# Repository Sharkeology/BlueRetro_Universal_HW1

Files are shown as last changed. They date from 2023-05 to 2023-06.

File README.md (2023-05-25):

# BlueRetro Universal HW1
A basic board meant to be used with the [BlueRetro project](https://github.com/darthcloud/BlueRetro) to simplify basic “HW1” internal installation in various supported consoles. Including onboard level shifting 3.3v regulation for consoles which don’t provide it.

### Bill of Materials
- [ESP-WROOM-32 Module](https://www.espressif.com/sites/default/files/documentation/esp32-wroom-32_datasheet_en.pdf)
- 2 x [TXS0108E 8-Bit Bi-directional, Level-Shifting, Voltage Translator](https://www.ti.com/lit/ds/symlink/txs0108e.pdf)
- 0805 1kΩ Pull-up Resistor for TXS0108E
- [AMS1117-3.3 3.3V 1A Low Dropout Voltage Regulator](http://www.advanced-monolithic.com/pdf/ds1117.pdf)
- 2 x 0805 Decoupling Capacitors for AMS1117 (I'm unsure of appropriate values, 1μF is what I used)

TXS0108EPWR Footprint and symbol courtesy of [SnapEDA](https://www.snapeda.com/parts/TXS0108EPWR/Texas%20Instruments/view-part/),
BlueRetro logo created by [HumbleBazooka](https://twitter.com/humblebazooka).

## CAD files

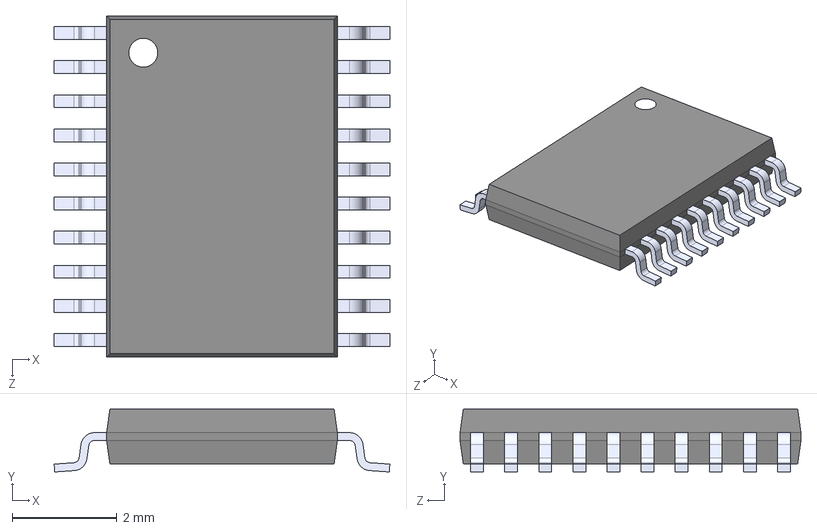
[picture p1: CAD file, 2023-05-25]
assets/TXS0108EPWR/TXS0108EPWR.step
6.40 x 1.20 x 6.50 mm

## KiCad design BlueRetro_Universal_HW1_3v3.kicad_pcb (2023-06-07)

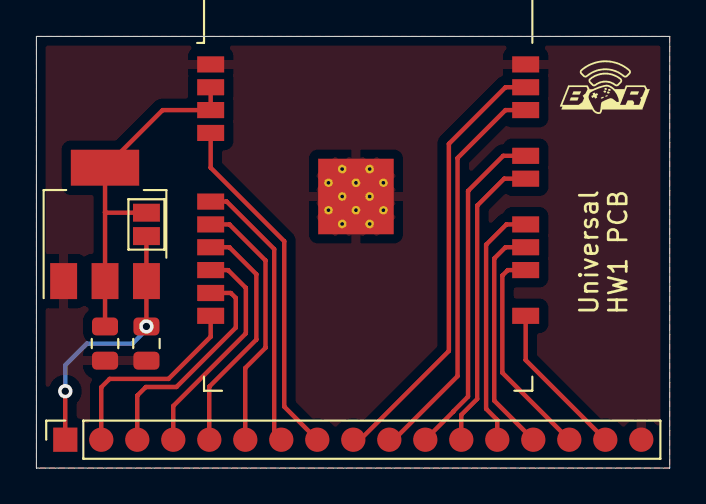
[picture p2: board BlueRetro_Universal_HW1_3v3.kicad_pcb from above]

Board: 2 copper layers, 35.2 x 24.0 mm, 6 parts (0 on the bottom side), 18 nets.

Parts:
C1, C2: 1uF; C_0805_2012Metric
J1: Conn_01x17; PinSocket_1x17_P2.00mm_Vertical
JP1: SolderJumper_2_Open; SolderJumper-2_P1.3mm_Open_Pad1.0x1.5mm
U1: AMS1117-3.3; SOT-223-3_TabPin2
U2: ESP32-WROOM-32

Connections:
+3V3: C2.1, JP1.2 (B), U1.2 (VO), U2.2 (VDD), U2.3 (EN)
+5V: C1.1, J1.1, JP1.1 (A), U1.3 (VI)
GND: C1.2, C2.2, J1.17, U1.1 (GND), U2.1 (GND), U2.38 (GND), U2.39 (GND)
IO3: J1.11, U2.34 (RXD0/IO3)
IO5: J1.15, U2.29 (IO5)
IO16: J1.16, U2.27 (IO16)
IO18: J1.14, U2.30 (IO18)
IO19: J1.13, U2.31 (IO19)
IO21: J1.12, U2.33 (IO21)
IO22: J1.10, U2.36 (IO22)
IO23: J1.9, U2.37 (IO23)
IO25: J1.4, U2.10 (IO25)
IO26: J1.3, U2.11 (IO26)
IO27: J1.2, U2.12 (IO27)
IO32: J1.6, U2.8 (IO32)
IO33: J1.5, U2.9 (IO33)
IO35: J1.7, U2.7 (IO35)
IO36: J1.8, U2.4 (SENSOR_VP)

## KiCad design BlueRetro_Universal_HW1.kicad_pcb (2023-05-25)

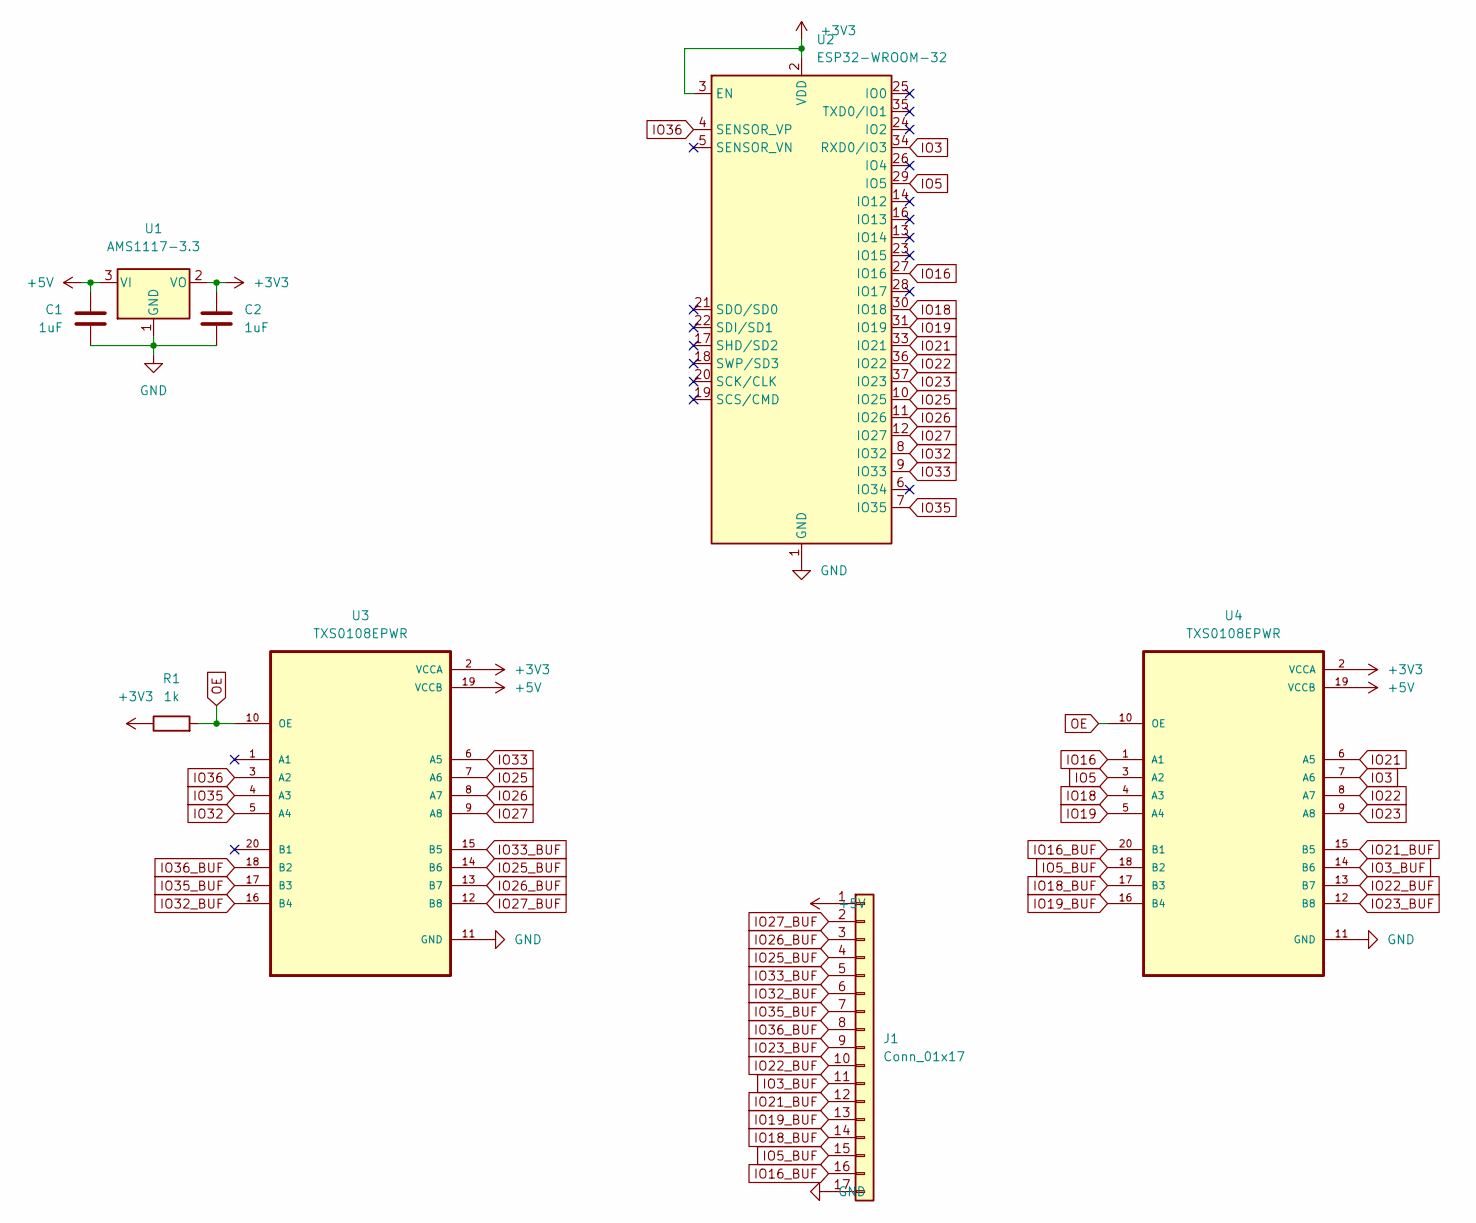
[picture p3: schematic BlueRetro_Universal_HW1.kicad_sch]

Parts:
C1, C2: 1uF; C_0805_2012Metric
J1: Conn_01x17; PinSocket_1x17_P2.00mm_Vertical
R1: 1k; R_0805_2012Metric
U1: AMS1117-3.3; SOT-223-3_TabPin2
U2: ESP32-WROOM-32
U3, U4: TXS0108EPWR; TSSOP-20_4.4x6.5mm_P0.65mm

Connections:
+3V3: C2.1, R1.1, U1.2 (VO), U2.2 (VDD), U2.3 (EN), U3.2 (VCCA), U4.2 (VCCA)
+5V: C1.1, J1.1, U1.3 (VI), U3.19 (VCCB), U4.19 (VCCB)
GND: C1.2, C2.2, J1.17, U1.1 (GND), U2.1 (GND), U2.15 (GND), U2.38 (GND), U2.39 (GND), U3.11 (GND), U4.11 (GND)
IO3: U2.34 (RXD0/IO3), U4.7 (A6)
IO3_BUF: J1.11, U4.14 (B6)
IO5: U2.29 (IO5), U4.3 (A2)
IO5_BUF: J1.15, U4.18 (B2)
IO16: U2.27 (IO16), U4.1 (A1)
IO16_BUF: J1.16, U4.20 (B1)
IO18: U2.30 (IO18), U4.4 (A3)
IO18_BUF: J1.14, U4.17 (B3)
IO19: U2.31 (IO19), U4.5 (A4)
IO19_BUF: J1.13, U4.16 (B4)
IO21: U2.33 (IO21), U4.6 (A5)
IO21_BUF: J1.12, U4.15 (B5)
IO22: U2.36 (IO22), U4.8 (A7)
IO22_BUF: J1.10, U4.13 (B7)
IO23: U2.37 (IO23), U4.9 (A8)
IO23_BUF: J1.9, U4.12 (B8)
IO25: U2.10 (IO25), U3.7 (A6)
IO25_BUF: J1.4, U3.14 (B6)
IO26: U2.11 (IO26), U3.8 (A7)
IO26_BUF: J1.3, U3.13 (B7)
IO27: U2.12 (IO27), U3.9 (A8)
IO27_BUF: J1.2, U3.12 (B8)
IO32: U2.8 (IO32), U3.5 (A4)
IO32_BUF: J1.6, U3.16 (B4)
IO33: U2.9 (IO33), U3.6 (A5)
IO33_BUF: J1.5, U3.15 (B5)
IO35: U2.7 (IO35), U3.4 (A3)
IO35_BUF: J1.7, U3.17 (B3)
IO36: U2.4 (SENSOR_VP), U3.3 (A2)
IO36_BUF: J1.8, U3.18 (B2)
OE: R1.2, U3.10 (OE), U4.10 (OE)

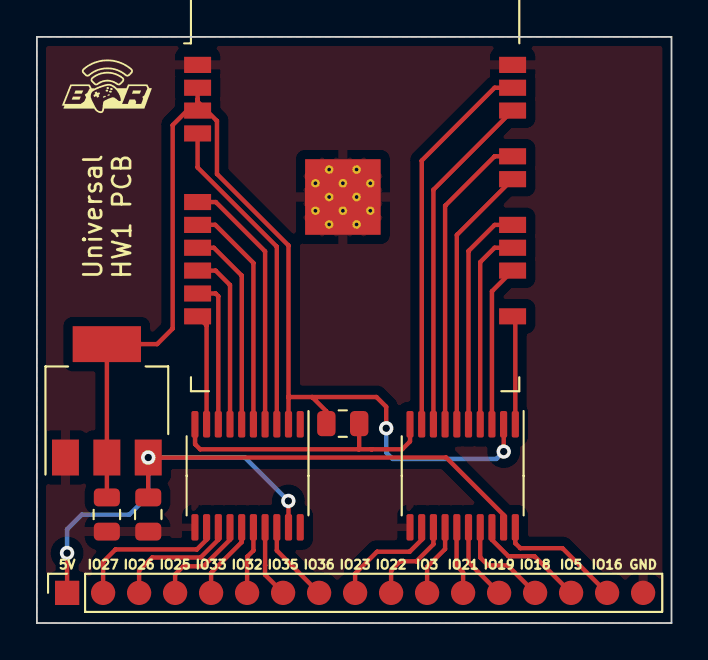
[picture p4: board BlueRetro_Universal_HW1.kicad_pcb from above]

Board: 2 copper layers, 35.3 x 32.6 mm, 8 parts (0 on the bottom side), 34 nets.

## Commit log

2023-05-25 Update README.md
    included attributions for footprints and logos
2023-06-07 Added 3v3 logic variant
    An additional board meant for more modern consoles whose controller buses use 3.3v logic has been uploaded. AMS1117 regulator still included for consoles without easily attainable 3.3v source (Sega D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
    [BlueRetro_Universal_HW1-B_Cu.gbr, BlueRetro_Universal_HW1-B_Mask.gbr, BlueRetro_Universal_HW1-B_Paste.gbr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]
